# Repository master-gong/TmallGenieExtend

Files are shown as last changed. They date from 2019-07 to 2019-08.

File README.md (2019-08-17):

# TmallGenieExtend

天猫精灵 方糖改装，扩展AUX、FM、Bluetooth音频输出
--------------------------------

全部开发资料。

改装教程：https://post.smzdm.com/p/a83dm967/

改装后

软件开发IDE：

Atollic TrueSTUDIO® for STM32, Built on Eclipse Neon.1a.

Version: 9.3.0 

BSP工程生成软件：

STM32CubeMX   Version 5.1.0

如果只下载固件，不进行二次开发，就不需要安装上述软件，
下载方法参考：https://mastergong.cn/archives/136.html
需要使用jlink。

  [1]: http://a.zdmimg.com/201905/14/5cdae5cf9098d3444.jpg_fo742.jpg

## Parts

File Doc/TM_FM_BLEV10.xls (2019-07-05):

Bill of Materials |  |  | <Parameter Title not found>
Source Data From: |  | TM_FM_BLEV10.PrjPCB
Project: |  | TM_FM_BLEV10.PrjPCB
Variant: |  | None
Creation Date: | 2019/5/7 星期二 | 上午 11:14:27
Print Date: | 43652 | 43652.0201
Footprint | Comment | LibRef | Designator | Description | Quantity
0402_C | 100nF (104) 10% 16V | 0402 100nF (104) 10% 16V | C1, C2, C3, C4, C8, C12, C13, C15, C18, C19, C21, C22 | 贴片电容 | 12 | 0.012248 | 0.146976 | 2 | 24
0402_C | 2.2nF (222) 10% 50V | 0402 2.2nF (222) 10% 50V | C5, C6 | 贴片电容 | 2 | 0.015175 | 0.03035 | 2 | 4
0402_C | 10uF (106) 20% 6.3V | 0402 10uF (106) 20% 6.3V | C7, C11, C14, C16, C24, C30, C39 | 贴片电容 | 7 | 0.132719 | 0.929033 | 2 | 14
0402_C | 2.2uF (225) 20% 50V | 0402 2.2nF (222) 10% 50V | C9, C10 | 贴片电容 | 2 | 0.026972 | 0.053944 | 2 | 4
CASE-B_3528 | 100uF (107) ±10% 6.3V | 3528 100uF (107) 10% 6.3V | C20, C23 | 钽电容 | 2 | 0.63 | 1.26 | 2 | 4
0402_C | 1.0uF (105) 10% 25V | 0402 1.0uF (105) 10% 25V | C27 | 贴片电容 | 1 | 0.087393 | 0.087393 | 2 | 2
0402_C | 20pF (200) 5% 50V | 0402 20pF (200) 5% 50V | C28, C29 | 贴片电容 | 2 | 0.018078 | 0.036156 | 2 | 4
0402_C | 1nF (102) 10% 50V | 0402 1nF (102) 10% 50V | C31 | 贴片电容 | 1 | 0.042192 | 0.042192 | 2 | 2
0402_C | 4.7uF (475) 20% 10V | 0402 4.7uF (475) 20% 10V | C32, C33 | 贴片电容 | 2 | 0.124 | 0.248 | 2 | 4
0603_C | 1nF (102) 10% 50V | 0603 1nF (102) 10% 50V | C34, C35, C36 | 贴片电容 | 3 | 0.041417 | 0.124251 | 2 | 6
0603_C | 6.8pF (6R8) 0.25pF 50V | 0603 6.8pF (6R8) 0.25pF 50V | C37 | 贴片电容 | 1 | 0.022886 | 0.022886 | 2 | 2
0402_C | 100pF (101) 5% 50V | 0402 100pF (101) 5% 50V | C38 | 贴片电容 | 1 | 0.033993 | 0.033993 | 2 | 2
PJ327A-无固定孔 | PJ-327A | PJ-327A | CON1 |  | 1 | 0.28 | 0.28 | 5 | 5
简易下载点 | HDR-1X4 | Header 4 | JP1 | 4P接插件 | 1 | 0 | 0 |  | 0
焊接点 | HDR-1X5 | Header 5 | JP2 | 5P接插件 | 1 | 0 | 0 |  | 0
单个焊接点 | HDR-1X1 | Header 1 | JP4 | 1P接插件 | 1 | 0.2 | 0.2 |  | 0
0603_L | 100nH ±5% 0603 | 0603 68nH 5% 0603 | L1 | 贴片电感 | 1 | 0.227955 | 0.227955 | 2 | 2
0603_L | 390nH ±5% | 0603 33nH 5% | L2 | 贴片电感 | 1 | 0.227955 | 0.227955 | 2 | 2
SOT-23(SOT-23-3) | SI2301CDS-T1-GE3 | SI2301CDS-T1-GE3 | Q1, Q2, Q3, Q4, Q5 | MOS(场效应管) | 5 | 0.18267 | 0.91335 | 3 | 15
SOT-23(SOT-23-3) | S9018 | SOT-23 2SC3356-T1B-A S/YS档 | Q6 | 三极管 | 1 | 0.069052 | 0.069052 | 3 | 3
0402_R | 10KΩ (1002) ±1% | 0402 10KΩ (1002) 1% | R1, R15, R16, R20, R21 | 贴片电阻 | 5 | 0.004553 | 0.022765 | 2 | 10
0402_R | 470Ω (4700) ±1% | 0402 470Ω (4700) 1% | R2, R3 | 贴片电阻 | 2 | 0.018789 | 0.037578 | 2 | 4
0402_R | 0Ω (0R0) ±1% | 0402 0Ω (0R0) 1% | R4, R5, R6, R7, R17, R19 | 贴片电阻 | 6 | 0 | 0 | 2 | 12
0402_R | 100KΩ (1003) ±1% | 0402 100KΩ (1003) 1% | R8, R9, R11, R13, R14, R23, R24 | 贴片电阻 | 7 | 0.006044 | 0.042308 | 2 | 14
0603_R | 0R ±25% 800mA | 0603 0Ω (0R0) 1% | R10, R22 | 贴片电阻 | 2 | 0.019996 | 0.039992 | 2 | 4
0402_R | 10Ω (10R0) ±1% | 0402 10Ω (10R0) 1% | R12 | 贴片电阻 | 1 | 0.018103 | 0.018103 | 2 | 2
0402_R | 47KΩ (4702) ±1% | 0402 47KΩ (4702) 1% | R18 | 贴片电阻 | 1 | 0.018025 | 0.018025 | 2 | 2
0402_Rx4 | 33Ω (330) ±5% | 0402*4 33Ω (330) 5% | Rp1 | 贴片排阻 | 1 | 0.026674 | 0.026674 | 8 | 8
TSW SMD-6*6*4.3 | 6x6x5 | TSW SMD-6x6 | SW1, SW2, SW3 | 贴片6x6轻触开关 | 3 | 0.05 | 0.15 | 4 | 12
LQFP32 7X7_M | STM32f030K6T6 | STM32f030K6T6 | U1 |  | 1 | 3.4 | 3.4 | 32 | 32
TSSOP20_N | PCM5102A | PCM5102A | U2 | 音频解码 | 1 | 7.5 | 7.5 | 20 | 20
蓝牙音频发送模组 | KCX_BT_EMITTER | KCX_BT_EMITTER | U3 |  | 1 | 15 | 15 | 11 | 11
0.96寸 彩色液晶 | 0.96寸 彩色液晶 | 0.96寸 彩色液晶 | U4 |  | 1 | 7.5 | 7.5 | 13 | 13
MSOP10_N | QN8027 | QN8027 | U5 |  | 1 | 1.09 | 1.09 | 10 | 10
SOT23-3M | XC6206 | XC6206 | VR1, VR2 |  | 2 | 0.116037 | 0.232074 | 3 | 6
SMD-3225_4P | 12MHZ 20PF 10PPM | SMD-3225_4P 12MHZ 20PF 10PPM | Y1 | 贴片晶振 | 1 | 0.79984 | 0.79984 | 4 | 4
 |  |  |  |  | 84 |  | 40.810845 |  | 263
Approved |  | Notes |  |  |  |  |  |  | 13.15
 |  |  |  |  |  | 成本 | 58.960845

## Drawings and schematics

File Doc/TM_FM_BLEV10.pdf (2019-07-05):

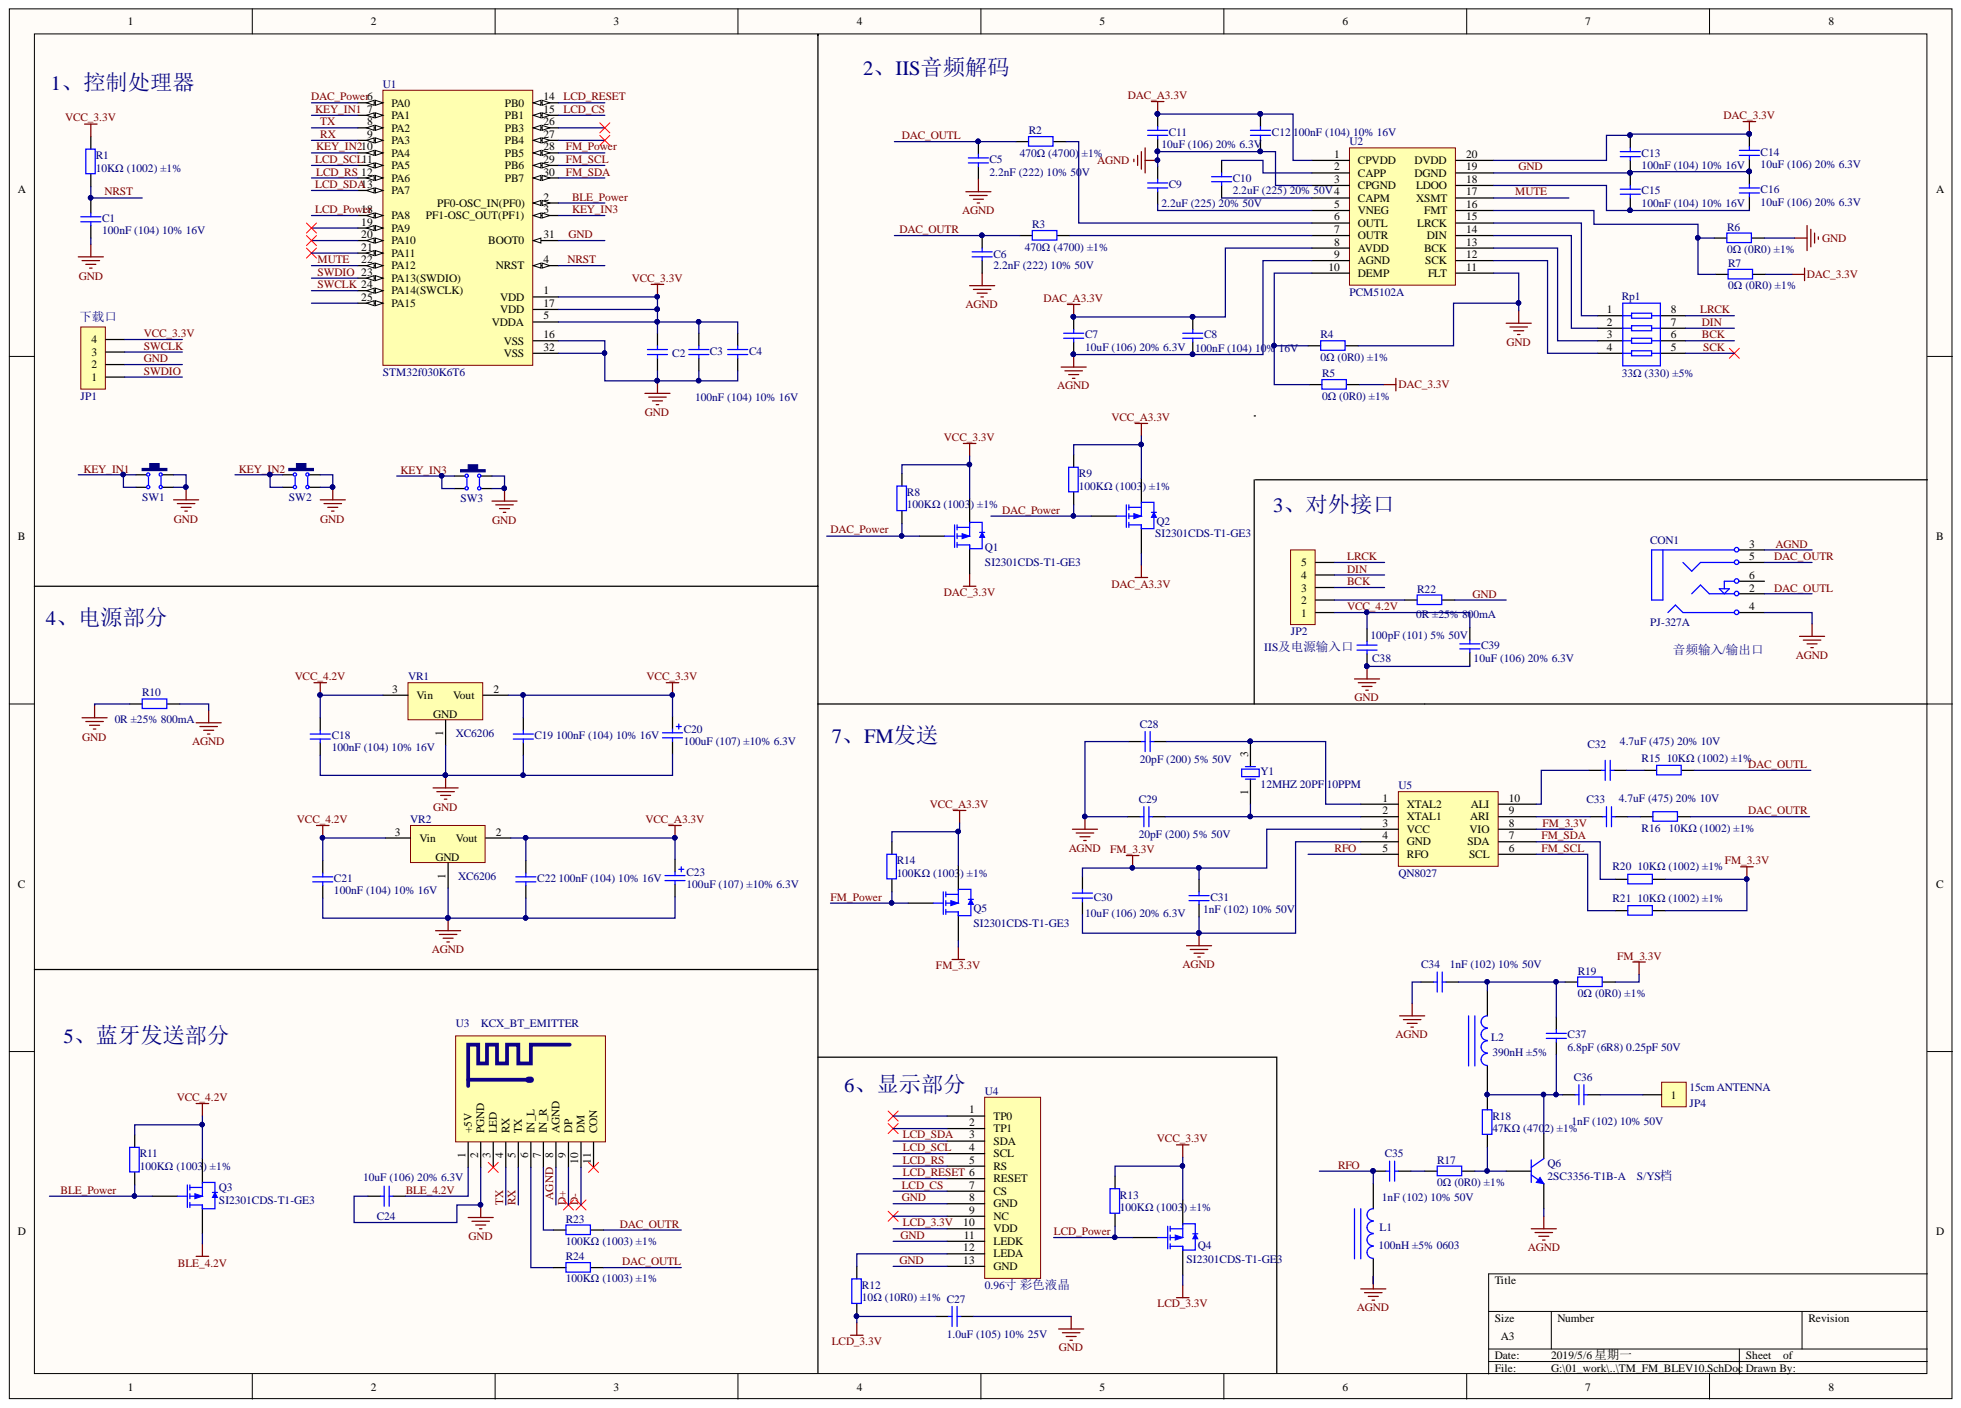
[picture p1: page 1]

XTAL1 2
VCC 3 | FM_3.3V

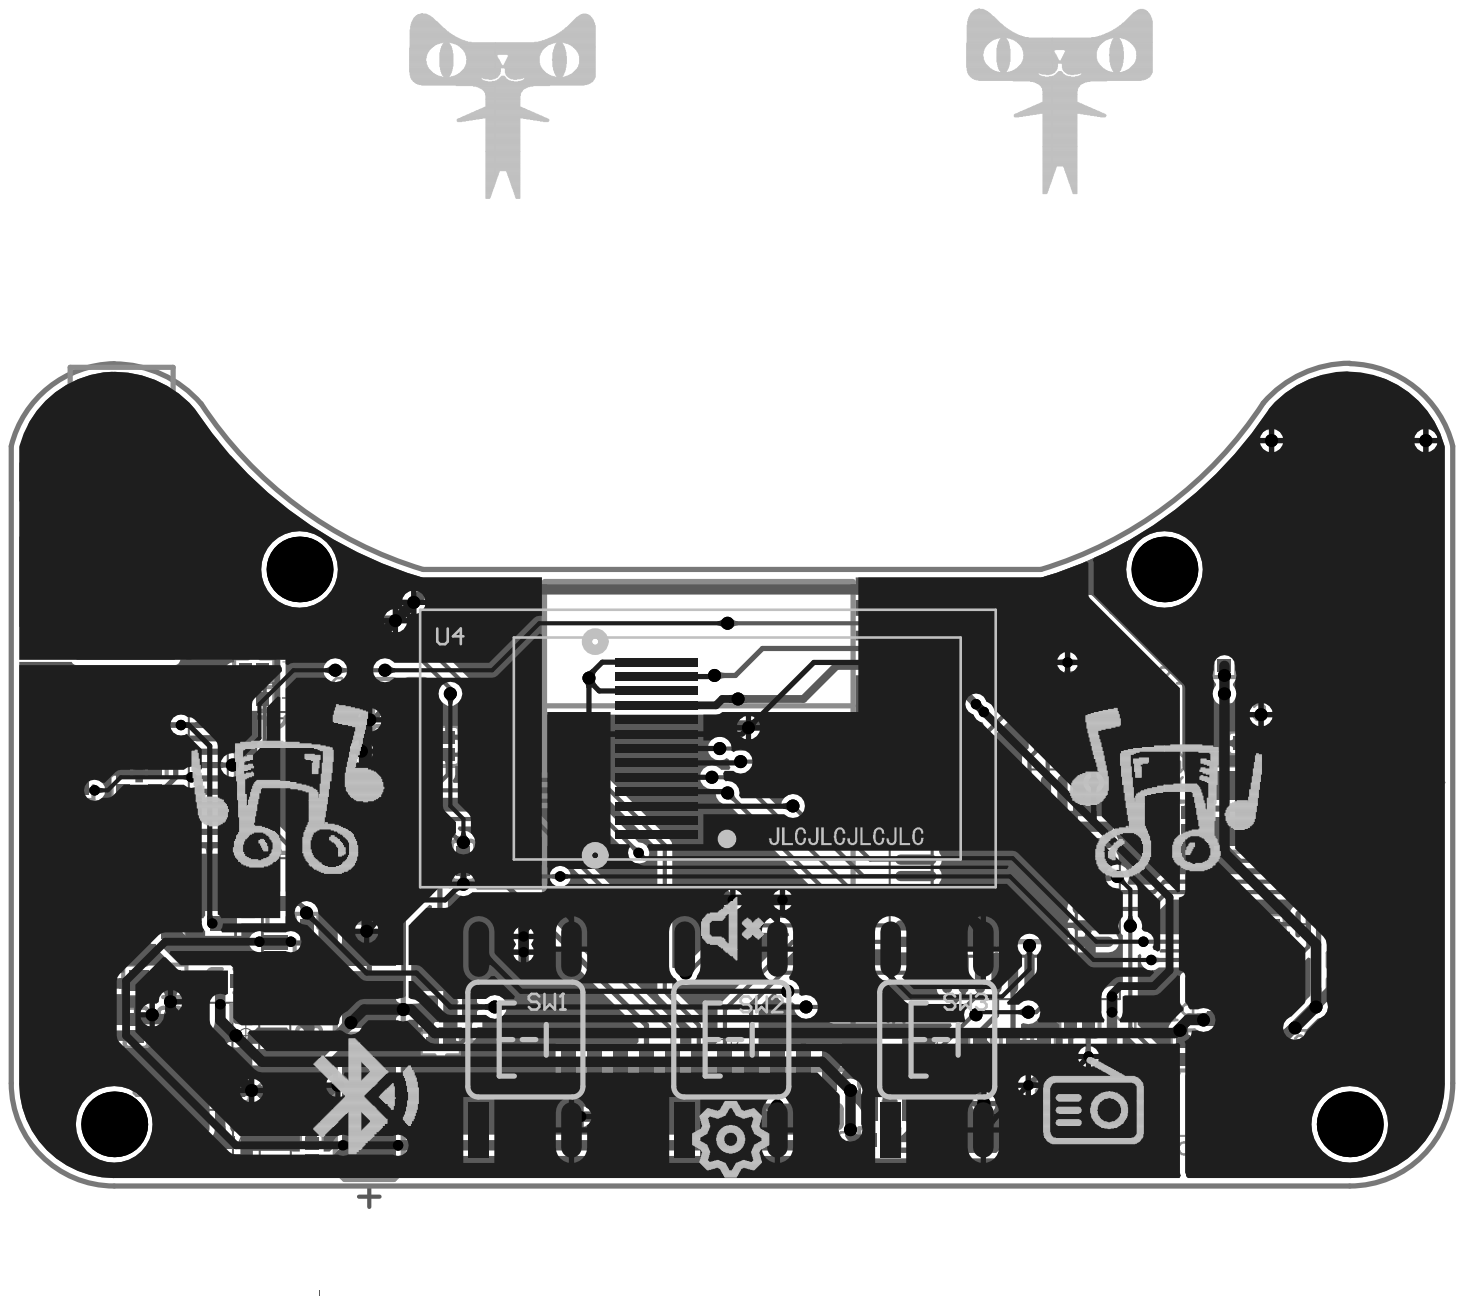
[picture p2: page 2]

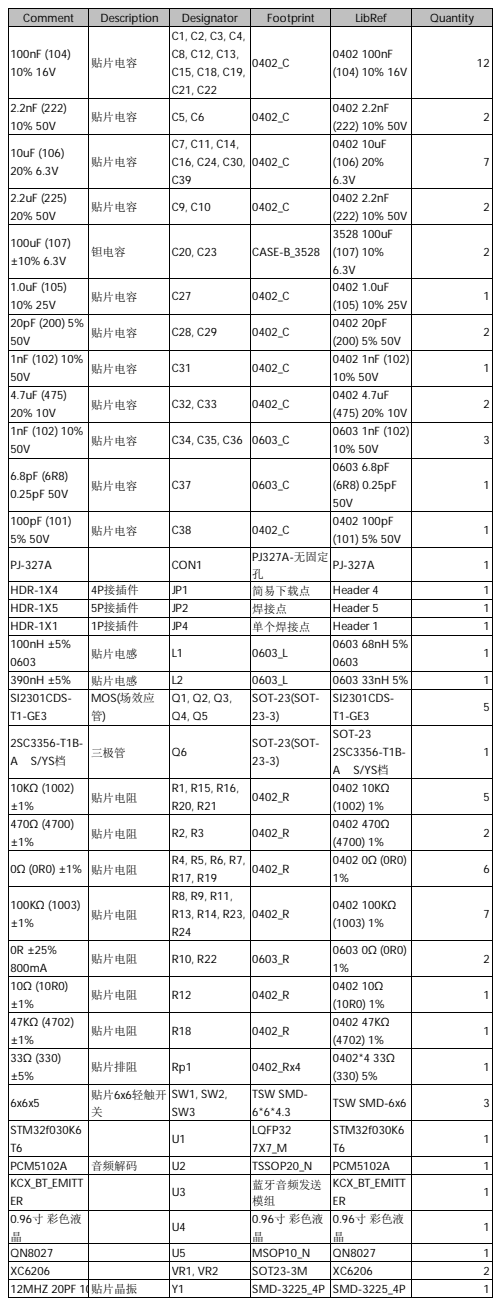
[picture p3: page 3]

Comment | Description | Designator | Footprint | LibRef | Quantity
100nF (104) 10% 16V | 贴片电容 | C1, C2, C3, C4, C8, C12, C13, C15, C18, C19, C21, C22 | 0402_C | 0402 100nF (104) 10% 16V | 12

2.2nF (222) 10% 50V | 贴片电容 | C5, C6 | 0402_C | 0402 2.2nF (222) 10% 50V | 2

10uF (106) 20% 6.3V | 贴片电容 | C7, C11, C14, C16, C24, C30, C39 | 0402_C | 0402 10uF (106) 20% 6.3V | 7

2.2uF (225) 20% 50V | 贴片电容 | C9, C10 | 0402_C | 0402 2.2nF (222) 10% 50V | 2

100uF (107) ±10% 6.3V | 钽电容 | C20, C23 | CASE-B_3528 | 3528 100uF (107) 10% 6.3V | 2

1.0uF (105) 10% 25V | 贴片电容 | C27 | 0402_C | 0402 1.0uF (105) 10% 25V | 1

20pF (200) 5% 50V | 贴片电容 | C28, C29 | 0402_C | 0402 20pF (200) 5% 50V | 2

1nF (102) 10% 50V | 贴片电容 | C31 | 0402_C | 0402 1nF (102) 10% 50V | 1

4.7uF (475) 20% 10V | 贴片电容 | C32, C33 | 0402_C | 0402 4.7uF (475) 20% 10V | 2

1nF (102) 10% 50V | 贴片电容 | C34, C35, C36 | 0603_C | 0603 1nF (102) 10% 50V | 3

6.8pF (6R8) 0.25pF 50V | 贴片电容 | C37 | 0603_C | 0603 6.8pF (6R8) 0.25pF 50V | 1

100pF (101) 5% 50V | 贴片电容 | C38 | 0402_C | 0402 100pF (101) 5% 50V | 1

PJ-327A | | CON1 | PJ327A-无固定 孔 | PJ-327A | 1

HDR-1X4 | 4P 接插件 | JP1 | 简易下载点 | Header 4 | 1
HDR-1X5 | 接插件 5P | JP2 | 焊接点 | Header 5 | 1
HDR-1X1 | 1P 接插件 | JP4 | 单个焊接点 | Header 1 | 1
100nH ±5% 0603 | 贴片电感 | L1 | 0603_L | 0603 68nH 5% 0603 | 1

390nH ±5% | 贴片电感 | L2 | 0603_L | 0603 33nH 5% | 1
SI2301CDS-T1-GE3 | MOS( 场效应 管 ) | Q1, Q2, Q3, Q4, Q5 | SOT-23(SOT-23-3) | SI2301CDS-T1-GE3 | 5

2SC3356-T1B-A S/YS 档 | 三极管 | Q6 | SOT-23(SOT-23-3) | SOT-23 2SC3356-T1B-A S/YS 档 | 1

10KΩ (1002) ±1% | 贴片电阻 | R1, R15, R16, R20, R21 | 0402_R | 0402 10KΩ (1002) 1% | 5

470Ω (4700) ±1% | 贴片电阻 | R2, R3 | 0402_R | 0402 470Ω (4700) 1% | 2

0Ω (0R0) ±1% | 贴片电阻 | R4, R5, R6, R7, R17, R19 | 0402_R | 0402 0Ω (0R0) 1% | 6

100KΩ (1003) ±1% | 贴片电阻 | R8, R9, R11, R13, R14, R23, R24 | 0402_R | 0402 100KΩ (1003) 1% | 7

0R ±25% 800mA | 贴片电阻 | R10, R22 | 0603_R | 0603 0Ω (0R0) 1% | 2

10Ω (10R0) ±1% | 贴片电阻 | R12 | 0402_R | 0402 10Ω (10R0) 1% | 1

47KΩ (4702) ±1% | 贴片电阻 | R18 | 0402_R | 0402 47KΩ (4702) 1% | 1

33Ω (330) ±5% | 贴片排阻 | Rp1 | 0402_Rx4 | 0402*4 33Ω (330) 5% | 1

6x6x5 | 贴片 6x6 轻触开 关 | SW1, SW2, SW3 | TSW SMD-6*6*4.3 | TSW SMD-6x6 | 3

STM32f030K6 T6 | | U1 | LQFP32 7X7_M | STM32f030K6 T6 | 1

PCM5102A | 音频解码 | U2 | TSSOP20_N | PCM5102A | 1
KCX_BT_EMITT ER | | U3 | 蓝牙音频发送 模组 | KCX_BT_EMITT ER | 1

0.96 寸 彩色液 晶 | | U4 | 0.96 寸 彩色液 晶 | 0.96 寸 彩色液 晶 | 1

QN8027 | | U5 | MSOP10_N | QN8027 | 1
XC6206 | | VR1, VR2 | SOT23-3M | XC6206 | 2
12MHZ 20PF 10 | 贴片晶振 | Y1 | SMD-3225_4P | SMD-3225_4P | 1

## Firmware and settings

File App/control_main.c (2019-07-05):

/*
 * control_main.c
 *
 *  Created on: 2019年4月13日
 *      Author: gongjunhui
 */


#include "control_main.h"
#include "control_bl.h"
#include "key_handle.h"
#include <string.h>
#include "gpio.h"
#include "st7735.h"
#include "qn8027.h"
#include "image.h"	//图片数据
#include "iwdg.h"


_audio_mode_em  em_audio_mode; //音频处理模式
_work_mode_em   em_work_mode;  //工作显示模式

_device_switch_em  em_FM_switch;//FM广播开关
_device_switch_em  em_BL_switch;//蓝牙开关
//static _device_switch_em  em_ADC_switch;//解码开关
static _device_switch_em  em_play_switch;//方糖播放开关

static  uint8_t  first_power_on_flag;//初次上电标志位
static  uint8_t  uc_lcd_init_state;//用于液晶初始化判断

static  uint16_t  uc_lcd_init_count;//用于液晶初始化计数
//static  uint8_t  lcd_display_refresh_flag; //显示标志

static  uint8_t  uc_fm_channel_old;  //fm发射频率 显示用 76Mhz - 108 Mhz 只取整数
static  _bl_status_em  em_bl_state_old;//蓝牙模块状态

static  uint8_t   falsh_write_flag;  //flash数据写标志
static  uint16_t  falsh_write_count; //flash数据写计数
static  uint16_t  menu_exit_count;       //菜单退出计数
static  uint16_t  dormancy_exit_count;   //休眠计数

/*******************************************
 * 函数名：flash_write_handle
 * 描述  ：  flash写操作
 * 输入  ：  无
 * 输出  ：  无
 * 履历  ：  V0.00  2019-5-2
********************************************/
static void flash_write_handle(void)
{
   FLASH_EraseInitTypeDef f;
   uint32_t PageError = 0;//设置PageError
   uint32_t ui_data = 0;//需要保存的数据
   uint32_t ui_dataq = 0;

   //byte1 byte2 byte3 byte4
   //byte4:bit7-bit4: 0001音频解码模式  0000音频输入模式
   //byte4:bit3-bit0: 0001方糖播放开      0000方糖播放关
   //byte3:bit7-bit4: 0001蓝牙开             0000蓝牙关
   //byte3:bit3-bit0: 0001FM开               0000FM关
   //byte2:FM频道

   HAL_FLASH_Unlock();//1、解锁FLASH
   //2、擦除FLASH
   //初始化FLASH_EraseInitTypeDef
   f.TypeErase = FLASH_TYPEERASE_PAGES;/*!<Pages erase only*/
   f.PageAddress = 0x08007C00;//起始地址
   f.NbPages = 1;//擦除1个页
   //调用擦除函数
   HAL_FLASHEx_Erase(&f, &PageError);
   ui_data = 0;
   if(em_audio_mode == AUDIO_DECODING){//音频处理模式 音频解码
	   ui_data |= 0x10;
   }
   //if(em_play_switch == SWITCH_OPEN){//方糖播放开关
	//   ui_data |= 0x01;
   //}
   if(em_BL_switch == SWITCH_OPEN){   //蓝牙开关
   	   ui_data |= 0x1000;
   }
   if(em_FM_switch == SWITCH_OPEN){   //FM开关
      ui_data |= 0x0100;
   }
   ui_dataq = uc_fm_channel;
   ui_data |= ((ui_dataq<<16)&0x00ff0000);//广播频道
   //3、对FLASH烧写
   HAL_FLASH_Program(FLASH_TYPEPROGRAM_WORD, 0x08007C00, ui_data);
   //4、锁住FLASH
   HAL_FLASH_Lock();
}
/*******************************************
 * 函数名：flash_read_handle
 * 描述  ：  flash读操作
 * 输入  ：  无
 * 输出  ：  无
 * 履历  ：  V0.00  2019-5-2
********************************************/
static void flash_read_handle(void)
{
   uint32_t ui_data = *(__IO uint32_t*)(0x08007C00);
   //byte4:bit3-bit0: 0001方糖播放开      0000方糖播放关
//   if((ui_data&0x0000000F)== 0x00000001){
//	   em_play_switch = SWITCH_OPEN;
//   }else{
//	   em_play_switch = SWITCH_CLOSE;
//   }
   //byte4:bit7-bit4: 0001音频解码模式  0000音频输入模式
   if((ui_data&0x000000F0)== 0x00000010){
	   em_audio_mode = AUDIO_DECODING;
   }else{
	   em_audio_mode = AUDIO_INPUT;
   }
   //byte3:bit7-bit4: 0001蓝牙开             0000蓝牙关
   if((ui_data&0x0000F000)== 0x00001000){
	   em_BL_switch = SWITCH_OPEN;
   }else{
	   em_BL_switch = SWITCH_CLOSE;
   }
   //byte3:bit3-bit0: 0001FM开               0000FM关
   if((ui_data&0x00000F00)== 0x00000100){
   	   em_FM_switch = SWITCH_OPEN;
   }else{
   	   em_FM_switch = SWITCH_CLOSE;
   }
   //byte2:FM频道
   uc_fm_channel = (ui_data>>16)&0xff;
   if(uc_fm_channel>108){
	   uc_fm_channel=108;
   }else if(uc_fm_channel<76){
	   uc_fm_channel=76;
   }

}
/*******************************************
 * 函数名：work_mode_screen_init
 * 描述  ：  屏幕初始化
 * 输入  ：  无
 * 输出  ：  无
 * 履历  ：  V0.00  2019-4-13
********************************************/
static void work_mode_screen_init(void)
{
	uint8_t disp_buff[5];
	if(uc_lcd_init_state == 0){
		OLED_RST_Clr();
		uc_lcd_init_count++;
		if(uc_lcd_init_count>20){
			uc_lcd_init_count = 0;
			uc_lcd_init_state = 1;
		}
		return;
	}else if(uc_lcd_init_state == 1){
		OLED_RST_Set();
		uc_lcd_init_count++;
		if(uc_lcd_init_count>30){
			uc_lcd_init_count = 0;
			uc_lcd_init_state = 2;
		}
		return;
	}
	lcd_init();
	MX_IWDG_Refresh();
	if(first_power_on_flag == 1){
		first_power_on_flag = 0;
		em_work_mode = WORK_MODE_POWER_ON; //开机logo
	}else{
		em_work_mode = WORK_MODE_NORMAL;   //正常模式
		uckey_value = KEY_NONE;   //没有键值
		//disp_clear_screen(BLACK);
		disp_rectangle(39,0,1,80,LGRAY);//
		disp_rectangle(120,0,1,80,LGRAY);
		disp_rectangle(40,0,80,80,DCYAN);

		if(em_FM_switch == SWITCH_OPEN){//FM广播开关
			disp_image_3232(128,45,gImage_FM,GRAYBLUE,BLACK);
			if(uc_fm_channel>99){//三位数
				disp_buff[0] = (uc_fm_channel/100)+0x30;
				disp_buff[1] = (uc_fm_channel/10%10)+0x30;
				disp_buff[2] = (uc_fm_channel%10)+0x30;
				disp_buff[3] = 0;
				display_gb1212(134,58,(const char*)disp_buff,BLUE,BLACK);//数字显示
			}else{ //二位数
				disp_buff[0] = (uc_fm_channel/10%10)+0x30;
				disp_buff[1] = (uc_fm_channel%10)+0x30;
				disp_buff[2] = 0;
				display_gb1212(141,58,(const char*)disp_buff,BLUE,BLACK);//数字显示
			}
		}else{
			disp_image_3232(128,45,gImage_FM,GRAY,BLACK);
		}
		if(em_BL_switch == SWITCH_OPEN){//蓝牙开关
			if(em_bl_state == BL_STATUS_LINK_OK){ //连接成功
				disp_image_3232(2,45,gImage_BL_ON,GRAYBLUE,BLACK);
			}else{
				disp_image_3232(2,45,gImage_BL_OFF,GRAYBLUE,BLACK);
			}
		}else{
			disp_image_3232(2,45,gImage_BL_OFF,GRAY,BLACK);
		}
		if(em_play_switch == SWITCH_OPEN){  //方糖播放开关
			disp_image_3232(2,5,gImage_audio,GRAYBLUE,BLACK);
		}else{
			disp_image_3232(2,5,gImage_audio,GRAY,BLACK);
		}
		if(em_audio_mode == AUDIO_DECODING){  //音频处理模式 音频解码
			disp_image_3232(128,5,gImage_headset,GRAYBLUE,BLACK);
			display_gb1616(64,2,"模式",BLUE,DCYAN);//LGRAY
			disp_image_8040(40,20,gImage_music,MAGENTA,DCYAN);//LIGHTGREEN
			display_gb1212(56,67,"方糖解码",GREEN,DCYAN);//RED
		}else{
			disp_image_3232(128,5,gImage_headset,GRAY,BLACK);
			display_gb1616(64,2,"模式",BLUE,DCYAN);//LGRAY
			disp_image_8040(40,20,gImage_35mm,YELLOW,DCYAN);//LIGHTGREEN
			display_gb1212(56,67,"音频输入",GREEN,DCYAN);//RED
		}
	}
}
/*******************************************
 * 函数名：work_mode_power_on
 * 描述  ：  屏幕logo显示
 * 输入  ：  无
 * 输出  ：  无
 * 履历  ：  V0.00  2019-4-13
********************************************/
static void work_mode_power_on(void)
{
	uint8_t disp_buff[5];
	uc_lcd_init_count++;
	if(uc_lcd_init_count==1){
		//disp_clear_screen(BLACK);
		disp_image_10080(31,0,gImage_logo,BLUE,BLACK);
		//display_gb2424(8,47,"mastergong.cn",BLUE);
	}else if(uc_lcd_init_count==(1000/10)){
		display_gb1616(20,30,"方糖配我更精彩",RED,BLACK);
	}else if(uc_lcd_init_count==(3000/10)){
		display_gb1616(132,60,"1.0",GREEN,BLACK);
	}else if(uc_lcd_init_count==(5000/10)){
		disp_clear_screen(BLACK);
	}else if(uc_lcd_init_count>(5000/10)){
		uc_lcd_init_count =0 ;
//		disp_QRcode(BLUE,WHITE);
//		display_gb1616(12,20,"改",RED);
//		display_gb1616(12,50,"装",RED);
//		display_gb1616(134,20,"教",RED);
//		display_gb1616(134,50,"程",RED);
		em_work_mode = WORK_MODE_NORMAL;   //正常模式
		uckey_value = KEY_NONE;   //没有键值

		//disp_clear_screen(BLACK);
		disp_rectangle(39,0,1,80,LGRAY);//
		disp_rectangle(120,0,1,80,LGRAY);
		disp_rectangle(40,0,80,80,DCYAN);

		if(em_FM_switch == SWITCH_OPEN){//FM广播开关
			disp_image_3232(128,45,gImage_FM,GRAYBLUE,BLACK);
			if(uc_fm_channel>99){//三位数
				disp_buff[0] = (uc_fm_channel/100)+0x30;
				disp_buff[1] = (uc_fm_channel/10%10)+0x30;
				disp_buff[2] = (uc_fm_channel%10)+0x30;
				disp_buff[3] = 0;
				display_gb1212(134,58,(const char*)disp_buff,BLUE,BLACK);//数字显示
			}else{ //二位数
				disp_buff[0] = (uc_fm_channel/10%10)+0x30;
				disp_buff[1] = (uc_fm_channel%10)+0x30;
				disp_buff[2] = 0;
				display_gb1212(141,58,(const char*)disp_buff,BLUE,BLACK);//数字显示
			}
		}else{
			disp_image_3232(128,45,gImage_FM,GRAY,BLACK);
		}
		if(em_BL_switch == SWITCH_OPEN){//蓝牙开关
			if(em_bl_state == BL_STATUS_LINK_OK){ //连接成功
				 disp_image_3232(2,45,gImage_BL_ON,GRAYBLUE,BLACK);
			}else{
				 disp_image_3232(2,45,gImage_BL_OFF,GRAYBLUE,BLACK);
			}
		}else{
			disp_image_3232(2,45,gImage_BL_OFF,GRAY,BLACK);
		}
		if(em_play_switch == SWITCH_OPEN){  //方糖播放开关
			disp_image_3232(2,5,gImage_audio,GRAYBLUE,BLACK);
		}else{
			disp_image_3232(2,5,gImage_audio,GRAY,BLACK);
		}
		if(em_audio_mode == AUDIO_DECODING){  //音频处理模式 音频解码
			disp_image_3232(128,5,gImage_headset,GRAYBLUE,BLACK);
			display_gb1616(64,2,"模式",BLUE,DCYAN);//LGRAY
			disp_image_8040(40,20,gImage_music,MAGENTA,DCYAN);//LIGHTGREEN
			display_gb1212(56,67,"方糖解码",GREEN,DCYAN);//RED
		}else{
			disp_image_3232(128,5,gImage_headset,GRAY,BLACK);
			display_gb1616(64,2,"模式",BLUE,DCYAN);//LGRAY
			disp_image_8040(40,20,gImage_35mm,YELLOW,DCYAN);//LIGHTGREEN
			display_gb1212(56,67,"音频输入",GREEN,DCYAN);//RED
		}
	}



}
/*******************************************
 * 函数名：work_mode_screen_close
 * 描述  ：  屏幕关闭
 * 输入  ：  无
 * 输出  ：  无
 * 履历  ：  V0.00  2019-4-13
********************************************/
static void work_mode_screen_close(void)
{
  LCD_POWER_OFF;
  LCD_SCL_CLR;
  LCD_SDA_CLR;
  LCD_RESET_CLR;
  LCD_RS_CLR;
  LCD_CS_CLR;
  //----------按键处理---------------
  if(uckey_value != KEY_NONE){  //有按键
	  uckey_value = KEY_NONE;
	  em_work_mode = WORK_MODE_SCREEN_INIT;  //液晶初始化
	  LCD_POWER_ON;
	  LCD_SCL_SET;
	  LCD_SDA_SET;
	  LCD_RESET_SET;
	  LCD_RS_SET;
	  LCD_CS_SET;
  }
}
/*******************************************
 * 函数名：work_mode_normal
 * 描述  ：  正常模式
 * 输入  ：  无
 * 输出  ：  无
 * 履历  ：  V0.00  2019-4-13
********************************************/
static void work_mode_normal(void)
{
  uint8_t disp_buff[5];

  task_qn8027_function();

  //--------休眠判断-------
  dormancy_exit_count++;   //休眠计数
  if(dormancy_exit_count >= (5*60*1000/10)){//5min
	  dormancy_exit_count=0; //休眠计数
	  em_work_mode = WORK_MODE_SCREEN_CLOSE; //息屏
  }
  //------- 静音判断 ------------
  if(em_play_switch == SWITCH_OPEN){//方糖播放开关
	  DAC_MTUE_OFF;
  }else{
	  DAC_MTUE_ON;
  }

  //-------Flash 存储部分操作------------
  if(falsh_write_flag == 0x5A){ //flash数据写标志
	  falsh_write_count++;
	  if(falsh_write_count >= (5*60*1000/10)){//5min
		  falsh_write_flag = 0;
		  flash_write_handle();//flash写操作
	  }
  }else{
	  falsh_write_count=0;
  }
  //----------解码部分电源控制----------------
  if(em_audio_mode == AUDIO_DECODING){ //音频解码
	  DAC_POWER_ON;
  }else{             //音频输入
	  DAC_POWER_OFF;
  }
  //------------蓝牙标志实时刷新----------------
  if(em_bl_state_old != em_bl_state){
	  if(em_bl_state == BL_STATUS_LINK_OK){ //连接成功
		  disp_image_3232(2,45,gImage_BL_ON,GRAYBLUE,BLACK);
	  }else{
	  	  disp_image_3232(2,45,gImage_BL_OFF,GRAYBLUE,BLACK);
	  }
      em_bl_state_old = em_bl_state;//记录蓝牙状态
  }
  //----------按键处理---------------
  if(uckey_value == KEY_FM_SHORT_PRESS){  //FM键 短按
	  uckey_value = KEY_NONE;
	  dormancy_exit_count=0; //休眠计数
	  falsh_write_flag = 0x5A; //flash数据写标志
	  if(em_FM_switch == SWITCH_OPEN){//FM广播开关
		  em_FM_switch = SWITCH_CLOSE;
		  disp_image_3232(128,45,gImage_FM,GRAY,BLACK);
	  }else{
		  em_FM_switch = SWITCH_OPEN;
		  disp_image_3232(128,45,gImage_FM,GRAYBLUE,BLACK);
		  if(uc_fm_channel>99){//三位数
			 disp_buff[0] = (uc_fm_channel/100)+0x30;
			 disp_buff[1] = (uc_fm_channel/10%10)+0x30;
			 disp_buff[2] = (uc_fm_channel%10)+0x30;
			 disp_buff[3] = 0;
			 display_gb1212(134,58,(const char*)disp_buff,BLUE,BLACK);//数字显示
		  }else{ //二位数
			 disp_buff[0] = (uc_fm_channel/10%10)+0x30;
			 disp_buff[1] = (uc_fm_channel%10)+0x30;
			 disp_buff[2] = 0;
			 display_gb1212(141,58,(const char*)disp_buff,BLUE,BLACK);//数字显示
		  }

	  }
  }else if(uckey_value == KEY_FM_LONG_PRESS){  //FM键 长按
	  uckey_value = KEY_NONE;
	  dormancy_exit_count=0; //休眠计数
	  menu_exit_count = 0;   //菜单退出计数
	  em_work_mode = WORK_MODE_FM;  //FM设置
	  em_FM_switch = SWITCH_OPEN;
	  disp_clear_screen(BLACK);
	  uc_fm_channel_old = uc_fm_channel;//记录FM调频值
	  display_gb1616(55,2,"FM调频",RED,BLACK);//LGRAY
	  display_gb1212(4,65,"减",GREEN,BLACK);
	  display_gb1212(144,65,"加",GREEN,BLACK);
	  display_gb1212(66,65,"确定",GREEN,BLACK);
	  if(uc_fm_channel_old < 76){//保护
		  uc_fm_channel_old=76;
	  }
	  if(uc_fm_channel_old>99){//三位数
		  disp_buff[0] = (uc_fm_channel_old/100)+0x30;
		  disp_buff[1] = (uc_fm_channel_old/10%10)+0x30;
		  disp_buff[2] = (uc_fm_channel_old%10)+0x30;
		  disp_buff[3] = 0;
	  }else{ //二位数
		  disp_buff[0] = ' ';
		  disp_buff[1] = (uc_fm_channel_old/10%10)+0x30;
		  disp_buff[2] = (uc_fm_channel_old%10)+0x30;
		  disp_buff[3] = 0;
	  }
	  display_gb1616(42,30,(const char*)disp_buff,YELLOW,BLACK);//数字显示
	  display_gb1616(88,30,"MHz",BLUE,BLACK);//数字显示

  }else if(uckey_value == KEY_BL_SHORT_PRESS){  //蓝牙键 短按
	  uckey_value = KEY_NONE;
	  dormancy_exit_count=0; //休眠计数
	  falsh_write_flag = 0x5A; //flash数据写标志
	  if(em_BL_switch == SWITCH_OPEN){//蓝牙开关
		  em_BL_switch = SWITCH_CLOSE;
		  disp_image_3232(2,45,gImage_BL_OFF,GRAY,BLACK);
	  }else{
		  em_BL_switch = SWITCH_OPEN;
		  disp_image_3232(2,45,gImage_BL_OFF,GRAYBLUE,BLACK);
	  }
  }else if(uckey_value == KEY_BL_LONG_PRESS){  //蓝牙键 长按
	  uckey_value = KEY_NONE;
	  dormancy_exit_count=0; //休眠计数
	  menu_exit_count = 0;   //菜单退出计数
	  em_work_mode = WORK_MODE_BL;   //蓝牙设置
	  em_BL_switch = SWITCH_OPEN;
	  disp_clear_screen(BLACK);
	  display_gb1616(50,2,"蓝牙设置",RED,BLACK);//LGRAY
	  display_gb1212(4,65,"复位",GREEN,BLACK);
	  display_gb1212(135,65,"重启",GREEN,BLACK);
	  display_gb1212(66,65,"返回",GREEN,BLACK);

	  if(em_bl_state == BL_STATUS_RESET){ //出厂设置
	  	  display_gb1212(45,35,"数据清除中",YELLOW,BLACK);

	  }else if(em_bl_state == BL_STATUS_RESTART){ //重启中
		  display_gb1212(45,35,"詹重启中詹",YELLOW,BLACK);

	  }else if(em_bl_state == BL_STATUS_LINKING){ //连接中
		  display_gb1212(45,35,"詹连接中詹",YELLOW,BLACK);//

	  }else{//连接成功
		  display_gb1212(45,35,"詹连接成功",BLUE,BLACK);//
	  }
	  em_bl_state_old = em_bl_state;//记录蓝牙状态

  }else if(uckey_value == KEY_MAIN_SHORT_PRESS){  //主键 短按
	  uckey_value = KEY_NONE;
	  dormancy_exit_count=0; //休眠计数
	  //falsh_write_flag = 0x5A; //flash数据写标志
	  if(em_play_switch == SWITCH_OPEN){  //方糖播放开关
		  em_play_switch = SWITCH_CLOSE;
		  disp_image_3232(2,5,gImage_audio,GRAY,BLACK);
	  }else{
		  em_play_switch = SWITCH_OPEN;
		  disp_image_3232(2,5,gImage_audio,GRAYBLUE,BLACK);
	  }
  }else if(uckey_value == KEY_MAIN_LONG_PRESS){   //主键 长按
	  uckey_value = KEY_NONE;
	  dormancy_exit_count=0; //休眠计数
	  falsh_write_flag = 0x5A; //flash数据写标志
	  if(em_audio_mode == AUDIO_DECODING){  //音频处理模式 音频解码
		  em_audio_mode = AUDIO_INPUT;//音频输入
		  disp_image_3232(128,5,gImage_headset,GRAY,BLACK);
		  display_gb1616(64,2,"模式",BLUE,DCYAN);
		  disp_image_8040(40,20,gImage_35mm,YELLOW,DCYAN);//LIGHTGREEN
		  display_gb1212(56,67,"音频输入",GREEN,DCYAN);//RED
	  }else{
		  em_audio_mode = AUDIO_DECODING;////音频解码
		  disp_image_3232(128,5,gImage_headset,GRAYBLUE,BLACK);
		  display_gb1616(64,2,"模式",BLUE,DCYAN);//LGRAY
		  disp_image_8040(40,20,gImage_music,MAGENTA,DCYAN);//LIGHTGREEN
		  display_gb1212(56,67,"方糖解码",GREEN,DCYAN);//RED
	  }
  }
}
/*******************************************
 * 函数名：work_mode_bl_set
 * 描述  ：  蓝牙设置
 * 输入  ：  无
 * 输出  ：  无
 * 履历  ：  V0.00  2019-5-1
********************************************/
static void work_mode_bl_set(void)
{
	uint8_t disp_buff[5];
    if(em_bl_state_old != em_bl_state){
    	if(em_bl_state == BL_STATUS_RESET){ //出厂设置
    		display_gb1212(45,35,"数据清除中",YELLOW,BLACK);

    	}else if(em_bl_state == BL_STATUS_RESTART){ //重启中
    		display_gb1212(45,35,"詹重启中詹",YELLOW,BLACK);

    	}else if(em_bl_state == BL_STATUS_LINKING){ //连接中
    		display_gb1212(45,35,"詹连接中詹",YELLOW,BLACK);//

    	}else{//连接成功
    		display_gb1212(45,35,"詹连接成功",BLUE,BLACK);//
    	}
    	em_bl_state_old = em_bl_state;//记录蓝牙状态
    }

	//----------按键处理---------------
	if(uckey_value == KEY_FM_SHORT_PRESS){  //FM键 短按 +
	    uckey_value = KEY_NONE;
	    menu_exit_count = 0;   //菜单退出计数
	    bl_binding();

    }else if(uckey_value == KEY_BL_SHORT_PRESS){  //蓝牙键 短按 -
	    uckey_value = KEY_NONE;
	    menu_exit_count = 0;   //菜单退出计数
	    bl_bind_init();

    }else if(uckey_value == KEY_MAIN_SHORT_PRESS){  //主键 短按
	    uckey_value = KEY_NONE;
	    menu_exit_count = 0;   //菜单退出计数
	    em_work_mode = WORK_MODE_NORMAL; //正常模式
	 	//写入FLASH数据
        //disp_clear_screen(BLACK);
	 	disp_rectangle(39,0,1,80,LGRAY);//
	 	disp_rectangle(120,0,1,80,LGRAY);
	 	disp_rectangle(40,0,80,80,DCYAN);
	 	if(em_FM_switch == SWITCH_OPEN){//FM广播开关
	 	     disp_image_3232(128,45,gImage_FM,GRAYBLUE,BLACK);
	 	     if(uc_fm_channel>99){//三位数
	 	   	    disp_buff[0] = (uc_fm_channel/100)+0x30;
	 	   	    disp_buff[1] = (uc_fm_channel/10%10)+0x30;
	 	   	    disp_buff[2] = (uc_fm_channel%10)+0x30;
	 	   	    disp_buff[3] = 0;
	 	   	    display_gb1212(134,58,(const char*)disp_buff,BLUE,BLACK);//数字显示
	 	     }else{ //二位数
	 	   	    disp_buff[0] = (uc_fm_channel/10%10)+0x30;
	 	   	    disp_buff[1] = (uc_fm_channel%10)+0x30;
	 	   	    disp_buff[2] = 0;
	 	   	    display_gb1212(141,58,(const char*)disp_buff,BLUE,BLACK);//数字显示
	 	     }
	 	}else{
	 	   	 disp_image_3232(128,45,gImage_FM,GRAY,BLACK);
	 	}
	 	if(em_BL_switch == SWITCH_OPEN){//蓝牙开关
	 		if(em_bl_state == BL_STATUS_LINK_OK){ //连接成功
	 			disp_image_3232(2,45,gImage_BL_ON,GRAYBLUE,BLACK);
	 		}else{
	 			disp_image_3232(2,45,gImage_BL_OFF,GRAYBLUE,BLACK);
	 		}

	 	}else{
	 	    disp_image_3232(2,45,gImage_BL_OFF,GRAY,BLACK);
	 	}
	 	if(em_play_switch == SWITCH_OPEN){  //方糖播放开关
	 	    disp_image_3232(2,5,gImage_audio,GRAYBLUE,BLACK);
	 	}else{
	 	   	disp_image_3232(2,5,gImage_audio,GRAY,BLACK);
	 	}
	 	if(em_audio_mode == AUDIO_DECODING){  //音频处理模式 音频解码
	 	   	disp_image_3232(128,5,gImage_headset,GRAYBLUE,BLACK);
	 	   	display_gb1616(64,2,"模式",BLUE,DCYAN);//LGRAY
	 	   	disp_image_8040(40,20,gImage_music,MAGENTA,DCYAN);//LIGHTGREEN
	 	   	display_gb1212(56,67,"方糖解码",GREEN,DCYAN);//RED
	 	}else{
	 	   	disp_image_3232(128,5,gImage_headset,GRAY,BLACK);
	 	   	display_gb1616(64,2,"模式",BLUE,DCYAN);//LGRAY
	 	   	disp_image_8040(40,20,gImage_35mm,YELLOW,DCYAN);//LIGHTGREEN
	 	   	display_gb1212(56,67,"音频输入",GREEN,DCYAN);//RED
	 	}

	}else if(uckey_value == KEY_BL_LONG_PRESS){   //蓝牙键 长按
		uckey_value = KEY_NONE;
		menu_exit_count = 0;   //菜单退出计数
    }else if(uckey_value == KEY_FM_LONG_PRESS){   //FM键 长按
		uckey_value = KEY_NONE;
		menu_exit_count = 0;   //菜单退出计数
	}else if(uckey_value == KEY_MAIN_LONG_PRESS){ //主键 长按
		uckey_value = KEY_NONE;
		menu_exit_count = 0;   //菜单退出计数
	}
	menu_exit_count++;   //菜单退出计数
	if(menu_exit_count > (30*1000/10)){//30S无操作自动退出
		em_work_mode = WORK_MODE_NORMAL; //正常模式

		//disp_clear_screen(BLACK);
	    disp_rectangle(39,0,1,80,LGRAY);//
	    disp_rectangle(120,0,1,80,LGRAY);
		disp_rectangle(40,0,80,80,DCYAN);
		if(em_FM_switch == SWITCH_OPEN){//FM广播开关
			 disp_image_3232(128,45,gImage_FM,GRAYBLUE,BLACK);
			 if(uc_fm_channel>99){//三位数
			 	disp_buff[0] = (uc_fm_channel/100)+0x30;
			 	disp_buff[1] = (uc_fm_channel/10%10)+0x30;
			 	disp_buff[2] = (uc_fm_channel%10)+0x30;
			 	disp_buff[3] = 0;
			 	display_gb1212(134,58,(const char*)disp_buff,BLUE,BLACK);//数字显示
			 }else{ //二位数
			 	disp_buff[0] = (uc_fm_channel/10%10)+0x30;
			 	disp_buff[1] = (uc_fm_channel%10)+0x30;
			 	disp_buff[2] = 0;
			 	display_gb1212(141,58,(const char*)disp_buff,BLUE,BLACK);//数字显示
			 }
		}else{
			 	disp_image_3232(128,45,gImage_FM,GRAY,BLACK);
	    }
	    if(em_BL_switch == SWITCH_OPEN){//蓝牙开关
			 if(em_bl_state == BL_STATUS_LINK_OK){ //连接成功
			 	disp_image_3232(2,45,gImage_BL_ON,GRAYBLUE,BLACK);
			 }else{
			 	disp_image_3232(2,45,gImage_BL_OFF,GRAYBLUE,BLACK);
			 }
		}else{
			 disp_image_3232(2,45,gImage_BL_OFF,GRAY,BLACK);
		}
		if(em_play_switch == SWITCH_OPEN){  //方糖播放开关
			 disp_image_3232(2,5,gImage_audio,GRAYBLUE,BLACK);
		}else{
			 disp_image_3232(2,5,gImage_audio,GRAY,BLACK);
		}
	    if(em_audio_mode == AUDIO_DECODING){  //音频处理模式 音频解码
			 disp_image_3232(128,5,gImage_headset,GRAYBLUE,BLACK);
			 display_gb1616(64,2,"模式",BLUE,DCYAN);//LGRAY
			 disp_image_8040(40,20,gImage_music,MAGENTA,DCYAN);//LIGHTGREEN
			 display_gb1212(56,67,"方糖解码",GREEN,DCYAN);//RED
	    }else{
			 disp_image_3232(128,5,gImage_headset,GRAY,BLACK);
			 display_gb1616(64,2,"模式",BLUE,DCYAN);//LGRAY
			 disp_image_8040(40,20,gImage_35mm,YELLOW,DCYAN);//LIGHTGREEN
			 display_gb1212(56,67,"音频输入",GREEN,DCYAN);//RED
		}
	}
}
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

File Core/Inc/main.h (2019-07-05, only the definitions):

#define BL_POWER_Pin GPIO_PIN_0
#define BL_POWER_GPIO_Port GPIOF
#define KEY_IN3_Pin GPIO_PIN_1
#define KEY_IN3_GPIO_Port GPIOF
#define DAC_POWER_Pin GPIO_PIN_0
#define DAC_POWER_GPIO_Port GPIOA
#define KEY_IN1_Pin GPIO_PIN_1
#define KEY_IN1_GPIO_Port GPIOA
#define KEY_IN2_Pin GPIO_PIN_4
#define KEY_IN2_GPIO_Port GPIOA
#define LCD_SCL_Pin GPIO_PIN_5
#define LCD_SCL_GPIO_Port GPIOA
#define LCD_RS_Pin GPIO_PIN_6
#define LCD_RS_GPIO_Port GPIOA
#define LCD_SDA_Pin GPIO_PIN_7
#define LCD_SDA_GPIO_Port GPIOA
#define LCD_RESET_Pin GPIO_PIN_0
#define LCD_RESET_GPIO_Port GPIOB
#define LCD_CS_Pin GPIO_PIN_1
#define LCD_CS_GPIO_Port GPIOB
#define LCD_POWER_Pin GPIO_PIN_8
#define LCD_POWER_GPIO_Port GPIOA
#define DAC_MUTE_Pin GPIO_PIN_12
#define DAC_MUTE_GPIO_Port GPIOA
#define FM_POWER_Pin GPIO_PIN_5
#define FM_POWER_GPIO_Port GPIOB
#define FM_SCL_Pin GPIO_PIN_6
#define FM_SCL_GPIO_Port GPIOB
#define FM_SDA_Pin GPIO_PIN_7
#define FM_SDA_GPIO_Port GPIOB
#define LCD_POWER_ON   HAL_GPIO_WritePin(LCD_POWER_GPIO_Port, LCD_POWER_Pin, GPIO_PIN_RESET)
#define LCD_POWER_OFF  HAL_GPIO_WritePin(LCD_POWER_GPIO_Port, LCD_POWER_Pin, GPIO_PIN_SET)
#define LCD_SCL_CLR    HAL_GPIO_WritePin(LCD_SCL_GPIO_Port, LCD_SCL_Pin, GPIO_PIN_RESET)
#define LCD_SCL_SET    HAL_GPIO_WritePin(LCD_SCL_GPIO_Port, LCD_SCL_Pin, GPIO_PIN_SET)
#define LCD_SDA_CLR    HAL_GPIO_WritePin(LCD_SDA_GPIO_Port, LCD_SDA_Pin, GPIO_PIN_RESET)
#define LCD_SDA_SET    HAL_GPIO_WritePin(LCD_SDA_GPIO_Port, LCD_SDA_Pin, GPIO_PIN_SET)
#define LCD_RESET_CLR  HAL_GPIO_WritePin(LCD_RESET_GPIO_Port, LCD_RESET_Pin, GPIO_PIN_RESET)
#define LCD_RESET_SET  HAL_GPIO_WritePin(LCD_RESET_GPIO_Port, LCD_RESET_Pin, GPIO_PIN_SET)
#define LCD_RS_CLR     HAL_GPIO_WritePin(LCD_RS_GPIO_Port, LCD_RS_Pin, GPIO_PIN_RESET)
#define LCD_RS_SET     HAL_GPIO_WritePin(LCD_RS_GPIO_Port, LCD_RS_Pin, GPIO_PIN_SET)
#define LCD_CS_CLR     HAL_GPIO_WritePin(LCD_CS_GPIO_Port, LCD_CS_Pin, GPIO_PIN_RESET)
#define LCD_CS_SET     HAL_GPIO_WritePin(LCD_CS_GPIO_Port, LCD_CS_Pin, GPIO_PIN_SET)
#define BL_POWER_ON    HAL_GPIO_WritePin(BL_POWER_GPIO_Port, BL_POWER_Pin, GPIO_PIN_RESET)
#define BL_POWER_OFF   HAL_GPIO_WritePin(BL_POWER_GPIO_Port, BL_POWER_Pin, GPIO_PIN_SET)
#define FM_POWER_ON    HAL_GPIO_WritePin(FM_POWER_GPIO_Port, FM_POWER_Pin, GPIO_PIN_RESET)
#define FM_POWER_OFF   HAL_GPIO_WritePin(FM_POWER_GPIO_Port, FM_POWER_Pin, GPIO_PIN_SET)
#define BL_POWER_ON    HAL_GPIO_WritePin(BL_POWER_GPIO_Port, BL_POWER_Pin, GPIO_PIN_RESET)
#define BL_POWER_OFF   HAL_GPIO_WritePin(BL_POWER_GPIO_Port, BL_POWER_Pin, GPIO_PIN_SET)
#define DAC_POWER_ON   HAL_GPIO_WritePin(DAC_POWER_GPIO_Port, DAC_POWER_Pin, GPIO_PIN_RESET)
#define DAC_POWER_OFF  HAL_GPIO_WritePin(DAC_POWER_GPIO_Port, DAC_POWER_Pin, GPIO_PIN_SET)
#define DAC_MTUE_ON    HAL_GPIO_WritePin(DAC_MUTE_GPIO_Port, DAC_MUTE_Pin, GPIO_PIN_RESET)
#define DAC_MTUE_OFF   HAL_GPIO_WritePin(DAC_MUTE_GPIO_Port, DAC_MUTE_Pin, GPIO_PIN_SET)
#define TEST_FLASH     HAL_GPIO_TogglePin(TEXT_GPIO_Port, TEXT_Pin)
#define KEY_BL      HAL_GPIO_ReadPin(KEY_IN1_GPIO_Port,KEY_IN1_Pin)
#define KEY_FM      HAL_GPIO_ReadPin(KEY_IN3_GPIO_Port,KEY_IN3_Pin)
#define KEY_MAIN    HAL_GPIO_ReadPin(KEY_IN2_GPIO_Port,KEY_IN2_Pin)

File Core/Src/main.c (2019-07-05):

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

/* Includes ------------------------------------------------------------------*/
#include "main.h"
#include "iwdg.h"
#include "tim.h"
#include "usart.h"
#include "gpio.h"

/* USER CODE BEGIN Includes */
#include "control_main.h"
#include "key_handle.h"
#include "control_bl.h"
/* USER CODE END Includes */


/* USER CODE BEGIN PV */
volatile  uint8_t  ucTimestamp_ms=0;   /* 系统运行时间戳  */
/* USER CODE END PV */

void SystemClock_Config(void);
/**
  * @brief  The application entry point.
  * @retval int
  */
int main(void)
{
  /* MCU Configuration--------------------------------------------------------*/

  /* Reset of all peripherals, Initializes the Flash interface and the Systick. */
  HAL_Init();

  /* Configure the system clock */
  SystemClock_Config();

  /* Initialize all configured peripherals */
  MX_GPIO_Init();
  MX_TIM14_Init();
  MX_TIM16_Init();
  MX_USART1_UART_Init();
  MX_IWDG_Init();
  /* USER CODE BEGIN 2 */
  //启动定时器中断
   if(HAL_TIM_Base_Start_IT(&htim14) != HAL_OK){
      while(1);
   }
   if(HAL_TIM_Base_Start_IT(&htim16) != HAL_OK){
      while(1);
   }
   task_control_power_on_function();
  /* USER CODE END 2 */

  /* Infinite loop */
  /* USER CODE BEGIN WHILE */
  while (1)
  {
    /* USER CODE END WHILE */

    /* USER CODE BEGIN 3 */
	  task_control_main_function();
	  MX_IWDG_Refresh();
	  while(ucTimestamp_ms<10);
	  ucTimestamp_ms=0;
  }
  /* USER CODE END 3 */
}

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
/* USER CODE BEGIN 4 */
/********************************
 * 函数名：HAL_TIM_PeriodElapsedCallback
 * 说明:  定时器中断回调函数
 ********************************/
void HAL_TIM_PeriodElapsedCallback(TIM_HandleTypeDef *htim)
{
	if(htim == &htim14){//1ms
		ucTimestamp_ms++;
		UART_RxTime();
	}else if(htim == &htim16){//10ms
		ISR_key_handle_function();
	}
}
/* USER CODE END 4 */
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


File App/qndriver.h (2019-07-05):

/************************************************Copyright(c)***********************************
**                                   Quintic(Nanjing) Microelectronics Co,Ltd.
**                                   
**                                   http://www.quinticcorp.com
**
**--------------------File Info----------------------------------------------------------------
** File Name:                  qndriver.h
** subversion number:   160      
**----------------------------------------------------------------------------------------
************************************************************************************************/

#ifndef _QNDRIVER_H
#define _QNDRIVER_H
#define QN_8027
#define _QNFUNC_H_

#define CCS_RX  0
#define CCS_TX  1

#define FREQ2CHREG(freq)   ((freq-7600)/5)
#define CHREG2FREQ(ch)     (ch*5+7600)


#define _QNCOMMON_H_




#define QND_REG_NUM_MAX   19  // for qn8027
// crystal setting definition is not ready yet, please read datasheet to do setting accordingly
#define QND_CRYSTAL_REG             0x03 //?
#define QND_CRYSTAL_BIT_MASK        0x3f //?

#define QND_CRYSTAL_24MHZ           0x2b //?
#define QND_CRYSTAL_DEFAULT         QND_CRYSTAL_24MHZ



#define QND_MODE_SLEEP      0     
#define QND_MODE_WAKEUP     1
#define QND_MODE_DEFAULT    2
// RX / TX value is using upper 8 bit

#define QND_MODE_RX         0x8000
#define QND_MODE_TX         0x4000
// AM / FM value is using lower 8 bit 
// need to check datasheet to get right bit 
#define QND_MODE_FM         0x0000

#define BAND_FM        0


// tune
#define QND_FSTEP_50KHZ      0
#define QND_FSTEP_100KHZ      1
#define QND_FSTEP_200KHZ      2
// output format
#define QND_OUTPUT_ANALOG     0
#define QND_OUTPUT_IIS        1

// stereo mode
#define QND_TX_AUDIO_MONO              0x10
#define QND_TX_AUDIO_STEREO            0x00

#define QND_RX_AUDIO_MONO              0x20
#define QND_RX_AUDIO_STEREO            0x00

#define QND_CONFIG_MONO               0x01
#define QND_CONFIG_MUTE               0x02    
#define QND_CONFIG_SOFTCLIP           0x03
#define QND_CONFIG_AUTOAGC               0x04
#define QND_CONFIG_AGCGAIN               0x05    

#define QND_CONFIG_EQUALIZER           0x06    
#define QND_CONFIG_VOLUME               0x07          
#define QND_CONFIG_BASS_QUALITY       0x08
#define QND_CONFIG_BASS_FREQ           0x09
#define QND_CONFIG_BASS_GAIN           0x0a
#define QND_CONFIG_MID_QUALITY        0x0b
#define QND_CONFIG_MID_FREQ           0x0c
#define QND_CONFIG_MID_GAIN           0x0d
#define QND_CONFIG_TREBLE_FREQ        0x0e
#define QND_CONFIG_TREBLE_GAIN        0x0f

#define QND_ENABLE_EQUALIZER          0x10
#define QND_DISABLE_EQUALIZER         0x00


#define QND_CONFIG_AUDIOPEAK_DEV      0x11
#define QND_CONFIG_PILOT_DEV          0x12
#define QND_CONFIG_RDS_DEV            0x13

// input format
#define QND_INPUT_ANALOG     0
#define QND_INPUT_IIS        1

// i2s mode
#define QND_I2S_RX_ANALOG   0x00
#define QND_I2S_RX_DIGITAL  0x40
#define QND_I2S_TX_ANALOG   0x00
#define QND_I2S_TX_DIGITAL  0x20

//i2s clock data rate
#define QND_I2S_DATA_RATE_32K  0x00
#define QND_I2S_DATA_RATE_40K  0x10
#define QND_I2S_DATA_RATE_44K  0x20
#define QND_I2S_DATA_RATE_48K  0x30

//i2s clock Bit Wise
#define QND_I2S_BIT_8    0x00
#define QND_I2S_BIT_16   0x40
#define QND_I2S_BIT_24   0x80
#define QND_I2S_BIT_32   0xc0

//i2s Control mode
#define QND_I2S_MASTER   1
#define QND_I2S_SLAVE    0

//i2s Control mode
#define QND_I2S_MSB   0x00
#define QND_I2S_I2S   0x01
#define QND_I2S_DSP1  0x02
#define QND_I2S_DSP2  0x03
#define QND_I2S_LSB   0x04

#define QND_EQUALIZE_BASS    0x00
#define QND_EQUALIZE_MID    0x01
#define QND_EQUALIZE_TREBLE 0x02
// RDS, TMC
#define QND_EUROPE_FLEXIBILITY_DISABLE  0
#define QND_EUROPE_FLEXIBILITY_ENABLE   1
#define QND_RDS_OFF              0
#define QND_RDS_ON               1
#define QND_RDS_BUFFER_NOT_READY 0
#define QND_RDS_BUFFER_READY     1


#define CHIPID_QN8000    0x00
#define CHIPID_QN8005    0x20
#define CHIPID_QN8005B1  0x21
#define CHIPID_QN8006    0x30
#define CHIPID_QN8006LB  0x71
#define CHIPID_QN8007B1  0x11
#define CHIPID_QN8007    0x10
#define CHIPID_QN8006A1  0x30
#define CHIPID_QN8006B1  0x31
#define CHIPID_QN8016    0xe0
#define CHIPID_QN8016_1  0xb0
#define CHIPID_QN8015    0xa0
#define CHIPID_QN8065    0xa0
#define CHIPID_QN8067    0xd0
#define CHIPID_QN8065N   0xa0
#define CHIPID_QN8027    0x40
#define CHIPID_QN8025    0x80

#define RDS_INT_ENABLE  1
#define RDS_INT_DISABLE 0
//For antena impedance match
#define QND_HIGH_IMPEDANCE         1
#define QND_LOW_IMPEDANCE         0

#define QND_BAND_NUM     6
#define RSSINTHRESHOLD   4


typedef unsigned char  UINT8;             
typedef char           INT8;              
typedef unsigned short UINT16;            
typedef short          INT16;    




#define _QNCONFIG_H_



/********************* country selection**************/
#define COUNTRY_CHINA            0
#define COUNTRY_USA                1
#define COUNTRY_JAPAN            2
/************************EDN******************************/


/**********************************************************************************************
// Performance configuration 
***********************************************************************************************/


/**********************************************************************************************
// limitation configuration 
***********************************************************************************************/

#define QND_READ_RSSI_DELAY    10
#define QND_DELAY_BEFORE_UNMUTE  200
// auto scan
#define QND_MP_THRESHOLD       0x28   
#define PILOT_READ_OUT_DELAY_TIME 70
#define PILOT_SNR_READ_OUT_DELAY_TIME  (150-PILOT_READ_OUT_DELAY_TIME)
#define CH_SETUP_DELAY_TIME    300           


#define assert(str)
#define QND_LOG(a)
#define QND_LOGA(a,b)
#define QND_LOGB(a,b)
#define QND_LOGHEX(a,b)
#define _QNREG_H_
#define SYSTEM1       0x00
#define SYSTEM2       0x00
#define CH            0x01
#define CH_STEP       0x00
#define RDSD0         0x08
#define PAG_CAL       0x1f
#define CID2          0x06
#define RDSEN         0x80
#define TXREQ         0x20
#define CH_CH         0x03
#define RDSTXRDY      0x04
#define TX_FDEV       0x11  // FDEV on datasheet
#define _QNSYS_H_

#define CHANNEL_FILTER
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

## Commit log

2019-07-05 改装板代码 正式版1.00
2019-07-05 补充电路设计文件(.sch .pcb bom)
    [TM_FM_BLEV10.SchDoc, TM_FM_BLEV10.xls]
2019-07-05 添加开发软件说明，改装教程
2019-07-07 更新说明
2019-08-17 添加固件现在方式，通过jlink直接下载hex文件，不需要安装其他软件。

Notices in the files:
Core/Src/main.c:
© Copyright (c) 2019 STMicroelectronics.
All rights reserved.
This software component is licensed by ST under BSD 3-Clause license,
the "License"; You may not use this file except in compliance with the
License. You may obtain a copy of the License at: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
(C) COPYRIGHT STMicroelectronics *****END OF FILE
